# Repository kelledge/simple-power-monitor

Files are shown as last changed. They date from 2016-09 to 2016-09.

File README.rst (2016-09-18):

Error Calculations
------------------

Voltage Divider:
100KOhm +/- 0.1%, 75PPM/C (-40C -> 80C)
100KOhm +/-
Max: 100100.08008
min 99899.92008

Voltage Reference:

Min @ 20C: 2.495
Max @ 20C: 2.505

Temp Coef: 75PPM/C

Max Temp Err @ -40C: -11.228mV
Max Temp Err @ 80C: +11.272mV

Min @ -40C: 2.4837725 => -16.227mV error
Max @ +80C: 2.5162725 => +16.272mV error

Temperature Calculations
------------------------
The only part that dissipates enough energy to matter is the current sense
resistor.

Max Power Consumption
---------------------

*Current Sense:*

Resistor:
R_sense = 7mOhm
A_max = 6A
P_max = 252mW

Amp:
V_max = 72V
A_max = 190uA
P_max = 14mW

*Voltage Reference:*

Ref In:
REF_Z_in = 250kOhm
REF_V_in = 2.5V
REF_A_in = 10uA
REF_P    = 25uW

Resistor:
R_bias = 82kOhm
V_max = (30V - 2.5V)
P_max = V_max^2/R_bias => 9.2mW

Reference:

Total:

*Voltage Divider:*
1/6 Voltage Divider Network

Calculations:
R_eq = 120K
V_max = 30V
P_max = V_max^2/R_eq => 7.5mW

Parts List
----------

+----------+------------+---------------------------+---------------------+
| Quantity | Designator | Description               | Mouser SKU          |
+----------+------------+---------------------------+---------------------+
| 1        | U1         | Current sense amplifier   | 700-MAX4081SASA     |
| 1        | R1         | Current sense resistor    | 71-WSL20107L000FEA  |
| 1        | R2         | 1/6 voltage Divider       | 71-TNPW0805100KBEEA |
| 1        | R3         | 1/6 voltage Divider       | 71-TNPW080520K0BEEA |
| 1        | U2         | Voltage reference         | 584-ADR5041WBRTZ-R7 |
| 1        | R4         | Voltage reference bias    | 71-TNPW080582K0BEEA |
| 2        | J1/J2      | 2 pin terminal receptacle | 710-691311500102    |
| 2        | -          | 2 pin terminal plug       | 710-691351500002    |
| 1        | J3         | 3 pin terminal receptacle | 651-1926028         |
| 1        | -          | 3 pin terminal plug       | 651-1911978         |
+----------+------------+---------------------------+---------------------+

RAW
---
30V Max
12V/24V

+/- 6A
5/12/24 V Input

<= 1mA Power

V

5V -> 5A
0V -> -5A

Mount
-----
http://www.mouser.com/Search/ProductDetail.aspx?R=1201578virtualkey65100000virtualkey651-1201578

Current Sense
-------------

Calculations:

Resistor:
R_sense = 7mOhm
A_max = 6A
P_max = 252mW

Amp:
V_max = 72V
A_max = 190uA
P_max = 14mW

Ref:
REF_Z_in = 250kOhm
REF_V_in = 2.5V
REF_A_in = 10uA
REF_P    = 25uW

Parts:
7mOhm: http://www.mouser.com/ProductDetail/Vishay-Dale/WSL20107L000FEA/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
Amp: http://www.mouser.com/ProductDetail/Maxim-Integrated/MAX4081SASA+/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

Resistor: 500mW

-6A -> 0V
 0A -> 2.5V
+6A -> 5V

1mV out -> 2.4mA

Voltage Reference
-----------------
Bias: 82kOhm

Needs 60uA + 10uA: 70uA

(30-2.5)/80e3 -> 335uA
(12-2.5)/80e3 -> 115uA

REF_P_max = 9.2mW

Parts:
Ref: http://www.mouser.com/ProductDetail/Analog-Devices/ADR5041WBRTZ-R7/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
Bias: http://www.mouser.com/ProductDetail/Vishay/TNPW080582K0BEEA/?qs=222842oYAD9vR9R%252b93yFkQ%3d%3d

Divider
-------
1/6 Voltage Divider Network

Calculations:
R_eq = 120K
I_max = 250uA
P_max = 30mW

Parts:
100K: http://www.mouser.com/ProductDetail/Vishay/TNPW0805100KBEEA/?qs=sGAEpiMZZMtlubZbdhIBIFsxO9oIeGFUmiF5Rz3MCQ8%3d
20K: http://www.mouser.com/ProductDetail/Vishay/TNPW080520K0BEEA/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

25 PPM / C
0.1 %
125 mW (1/8 W)
150 V

Connectors
----------
3 Pin
Receptacle: http://www.mouser.com/ProductDetail/Phoenix-Contact/1926028/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
Plug: http://www.mouser.com/ProductDetail/Phoenix-Contact/1911978/?qs=sGAEpiMZZMvPvGwLNS6718PaoTt7FM7cq6nTDRCep18%3d

2 Pin
Receptacle: http://www.mouser.com/ProductDetail/Wurth-Electronics/691311500102/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
Plug: http://www.mouser.com/Search/ProductDetail.aspx?qs=7gQLVZk5cPkg%2frpRGyiXgA%3d%3d

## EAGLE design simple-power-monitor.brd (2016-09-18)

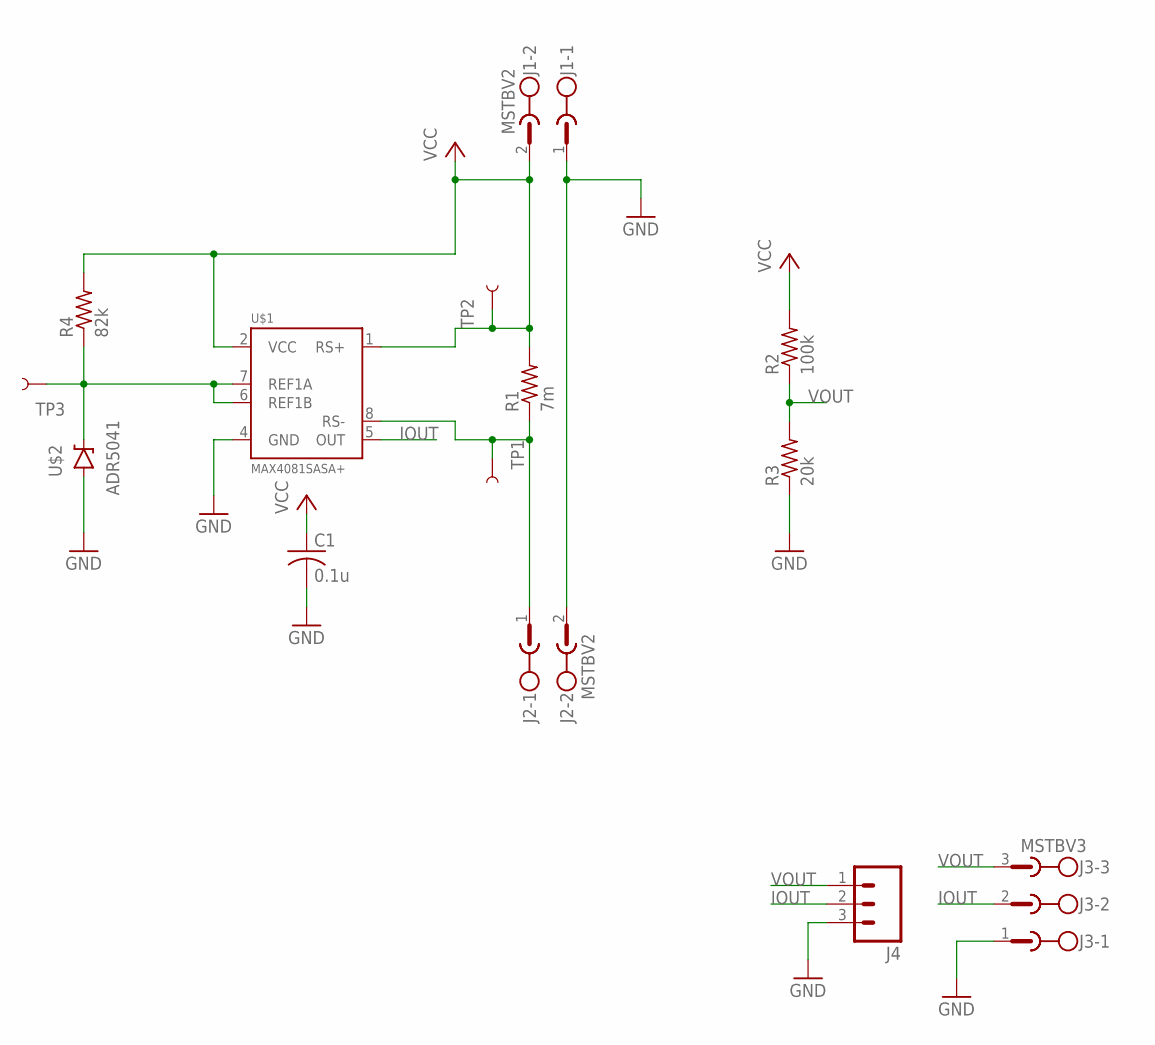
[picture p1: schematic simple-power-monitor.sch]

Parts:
C1: 0.1u; C0805K
J1, J2: MSTBV2
J3: MSTBV3
J4: M03PTH; 1X03
R1: 7m; R2010
R2: 100k; R0805
R3: 20k; R0805
R4: 82k; R0805
TP1, TP2, TP3: TEST-POINTTP_15TH_THRU; TP_15TH
U$1: MAX4081SASA+; SO8
U$2: ADR5041; SOT23-3

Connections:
GND: C1.2, J1.1, J2.2, J3.1, J4.3, R3.1, U$1.4 (GND), U$2.2 (A)
IOUT: J3.2, J4.2, U$1.5 (OUT)
unnamed: R4.1, TP3.P$1, U$1.6 (REF1B), U$1.7 (REF1A), U$2.1 (C)
RS+: J2.1, R1.1, TP1.P$1, U$1.8 (RS-)
VCC: C1.1, J1.2, R1.2, R2.2, R4.2, TP2.P$1, U$1.1 (RS+), U$1.2 (VCC)
VOUT: J3.3, J4.1, R2.1, R3.2

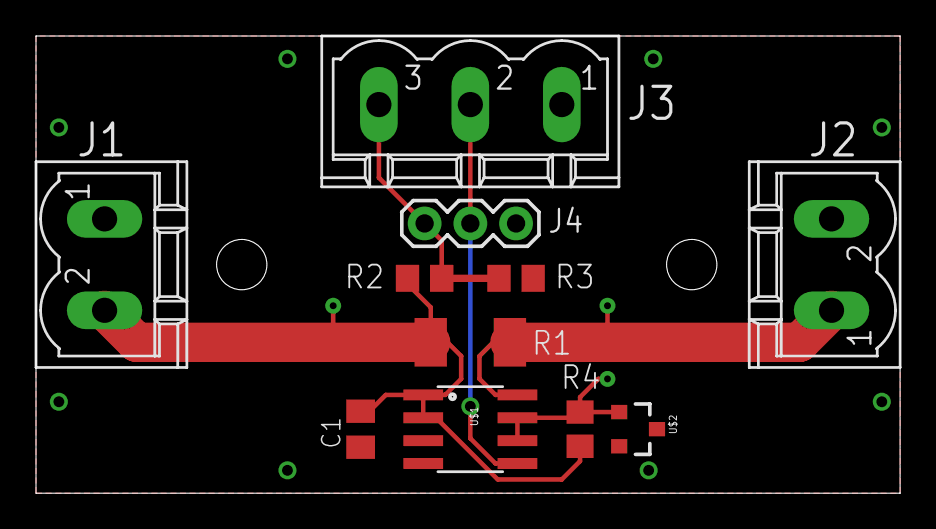
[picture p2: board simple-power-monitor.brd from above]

Board: 2 copper layers, 48.0 x 25.4 mm, 14 parts (0 on the bottom side), 6 nets.

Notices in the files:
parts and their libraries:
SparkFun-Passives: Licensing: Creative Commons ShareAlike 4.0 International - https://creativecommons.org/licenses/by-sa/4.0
